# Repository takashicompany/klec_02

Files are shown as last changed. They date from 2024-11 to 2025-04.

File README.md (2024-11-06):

# KLEC-02 "Gravity-36"

https://x.com/Hottyhottea/status/1843859533871058982


# 部品リスト

|画像|部品名|個数|備考|
|:--|:--|:--|:--|
||KLEC-02 PCB|1||
||[Pro Micro](https://shop.yushakobo.jp/products/21)|2|どれを買っていいか分からない場合は[コンスルー付きのセット](https://shop.yushakobo.jp/products/21)の購入を推奨します。|
||[タクトスイッチ](https://shop.yushakobo.jp/products/a0800ts-01-1)|2||
||[コンスルー](https://shop.yushakobo.jp/products/31)|4|PCBとPro Microを接続する端子です。Pro Microに付属するピンヘッダでの取り付けも可能ですが、作業ミスや故障した際の取り替えが容易になりますので、**コンスルーの使用を強く推奨します。ピンヘッダでの取り付けは当キーボードと当ビルドガイドではサポートしません。** コンスルーの必要な高さはPro Microによって異なりますので、販売元にご確認ください。コンスルーについての詳細な説明は[こちら](https://scrapbox.io/self-made-kbds-ja/%E3%82%B3%E3%83%B3%E3%82%B9%E3%83%AB%E3%83%BC)をご一読ください。併せて[取り付け方の説明](https://yushakobo.zendesk.com/hc/ja/articles/360044233974-%E3%82%B3%E3%83%B3%E3%82%B9%E3%83%AB%E3%83%BC-%E3%82%B9%E3%83%97%E3%83%AA%E3%83%B3%E3%82%B0%E3%83%94%E3%83%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)も目を通しておくと作業がスムーズに進められます。|
||[スイッチソケット MX用](https://shop.yushakobo.jp/products/a01ps)|36|使用せずとも、PCBとキースイッチをハンダ付けすることで取り付けは可能ですが、メンテナンス性と組み立て手順を間違えた際のリカバリーを考慮すると、スイッチソケットを使用することを推奨します。|
||[MX互換キースイッチ](https://shop.yushakobo.jp/collections/all-switches)|36||
||[MX互換キーキャップ](https://shop.yushakobo.jp/collections/keycaps)|36|[こちら](https://www.keyboard-layout-editor.com/#/gists/d532e57cda0be36ffc0e33e7f8f69d8d)から各キーのサイズを確認できます。|
||[ウレタンクッション](https://shop.yushakobo.jp/products/a0800ur-01-6)|12|数はお好みで増減させてください。|
||アクリルケース|1|[こちらのデータ](https://github.com/takashicompany/klec_02/blob/master/case/klec_02_a4_yushakobo.ai)を遊舎工房の[レーザー加工サービス](https://shop.yushakobo.jp/products/lasercut?variant=48787700744423)にてカット依頼するなどして製造してください。後日に[キーボードアクリルプレート](https://shop.yushakobo.jp/products/keyboard_acrylic_plate)に追加予定です。|
||[M2スペーサー](https://shop.yushakobo.jp/products/a0800c2?variant=37665435222177)|12|長さはお好みで調整してください。Pro Microなどにもよりますが、7mm~10mmぐらいがオススメです。|
||[M2ネジ 5mm](https://shop.yushakobo.jp/products/a0800n2?variant=37665432993953)|24||

# ファームウェア
QMK Firmwareへの[プルリクエストはこちら](https://github.com/qmk/qmk_firmware/pull/24559)です。

VIAに対応したファームウェアは[こちら](https://github.com/takashicompany/klec_02/blob/master/via/takashicompany_klec_02_via.hex)です。ソースコードは[こちら](https://github.com/takashicompany/qmk_firmware/tree/master/keyboards/takashicompany/klec_02/keymaps/via)になります。

[RemapからWebブラウザを用いたファームウェアの書き込み](https://remap-keys.app/keyboards/jiZA8wP7nL4qwY1EUZ8j)とキーマップの変更が可能です。

~2024年11月5日現在、Remapの審査中ですのでRemapでキーマップを変更したい場合は[こちらのjsonファイル](https://github.com/takashicompany/klec_02/blob/master/via/via.json)をアップロードしてご利用ください。~

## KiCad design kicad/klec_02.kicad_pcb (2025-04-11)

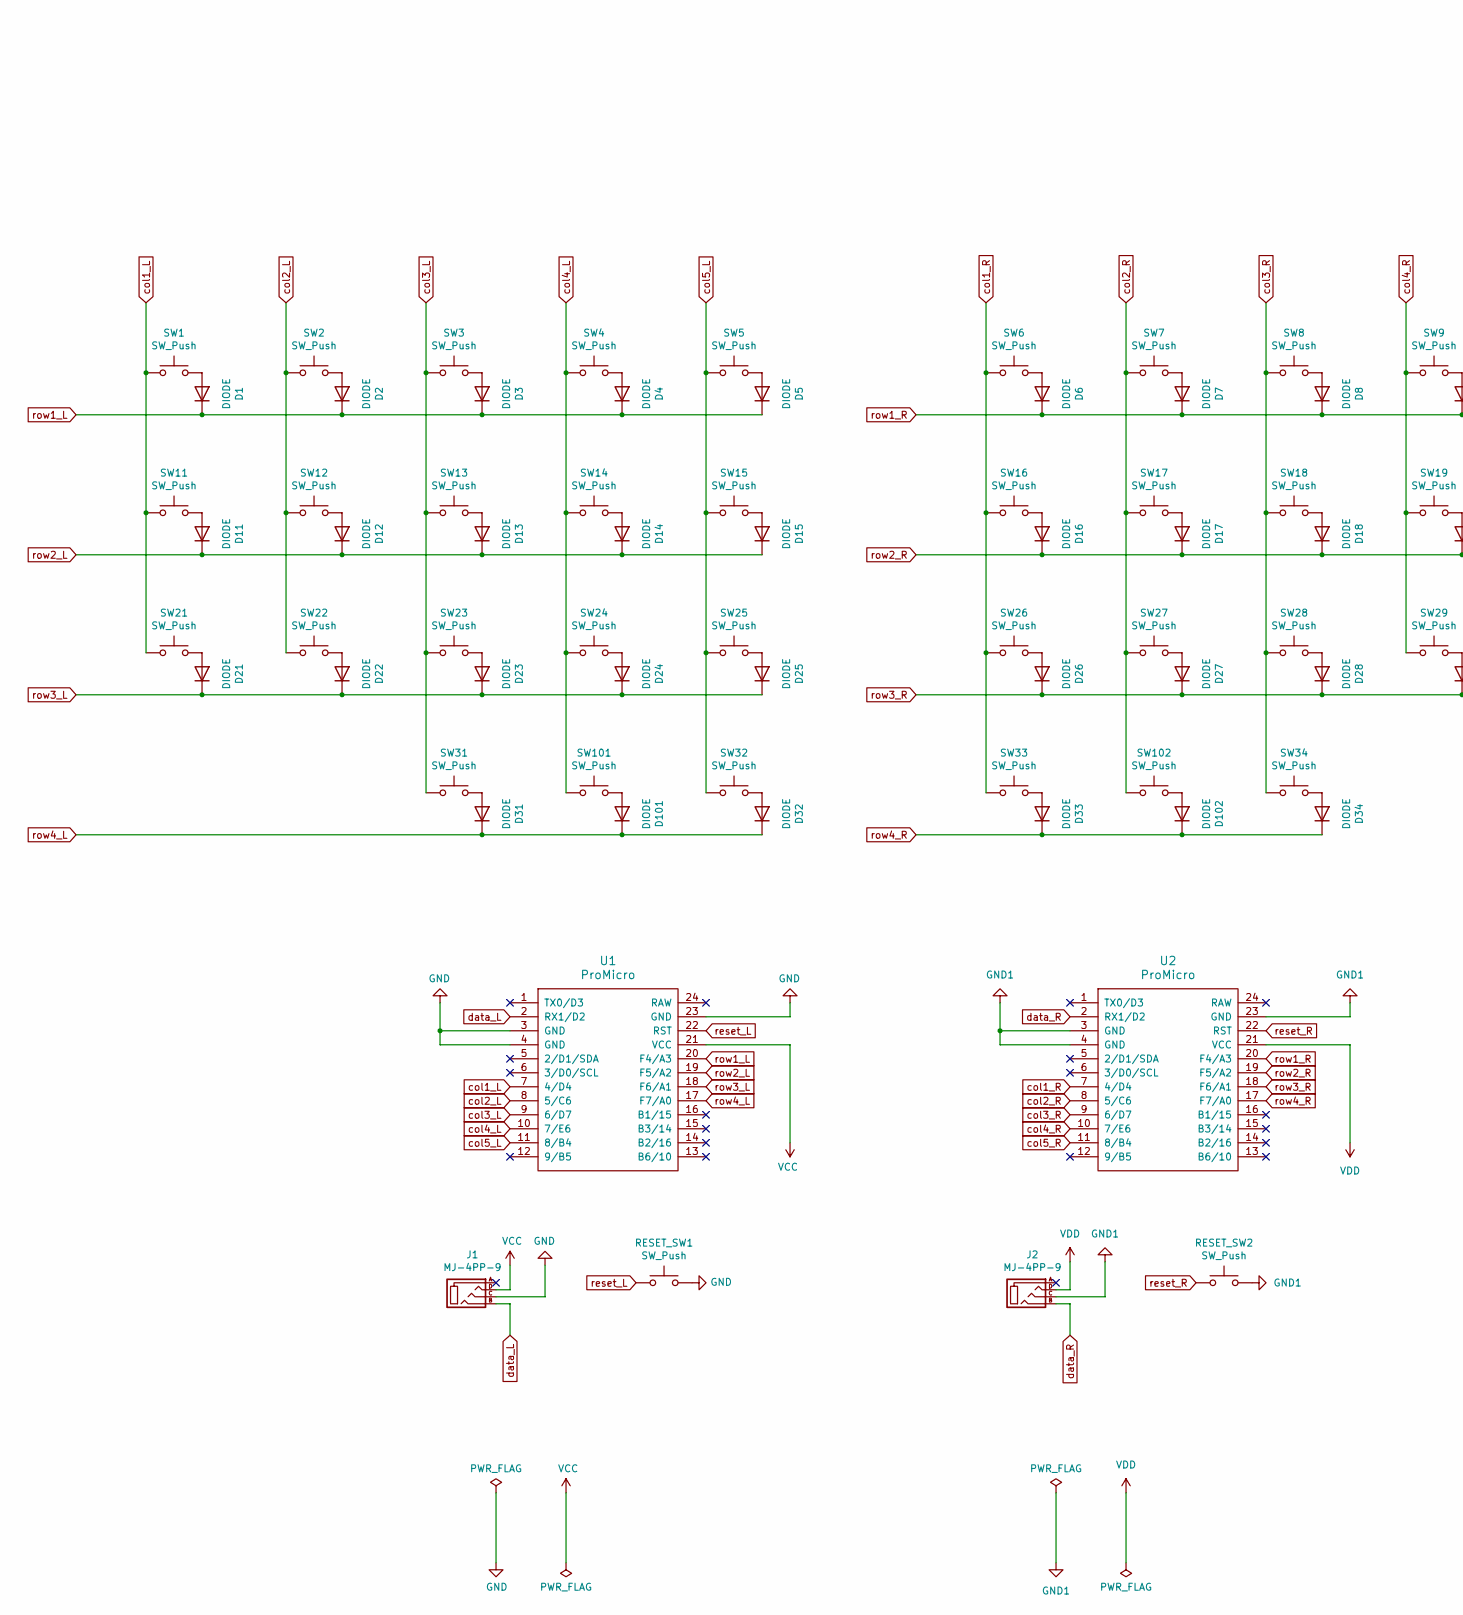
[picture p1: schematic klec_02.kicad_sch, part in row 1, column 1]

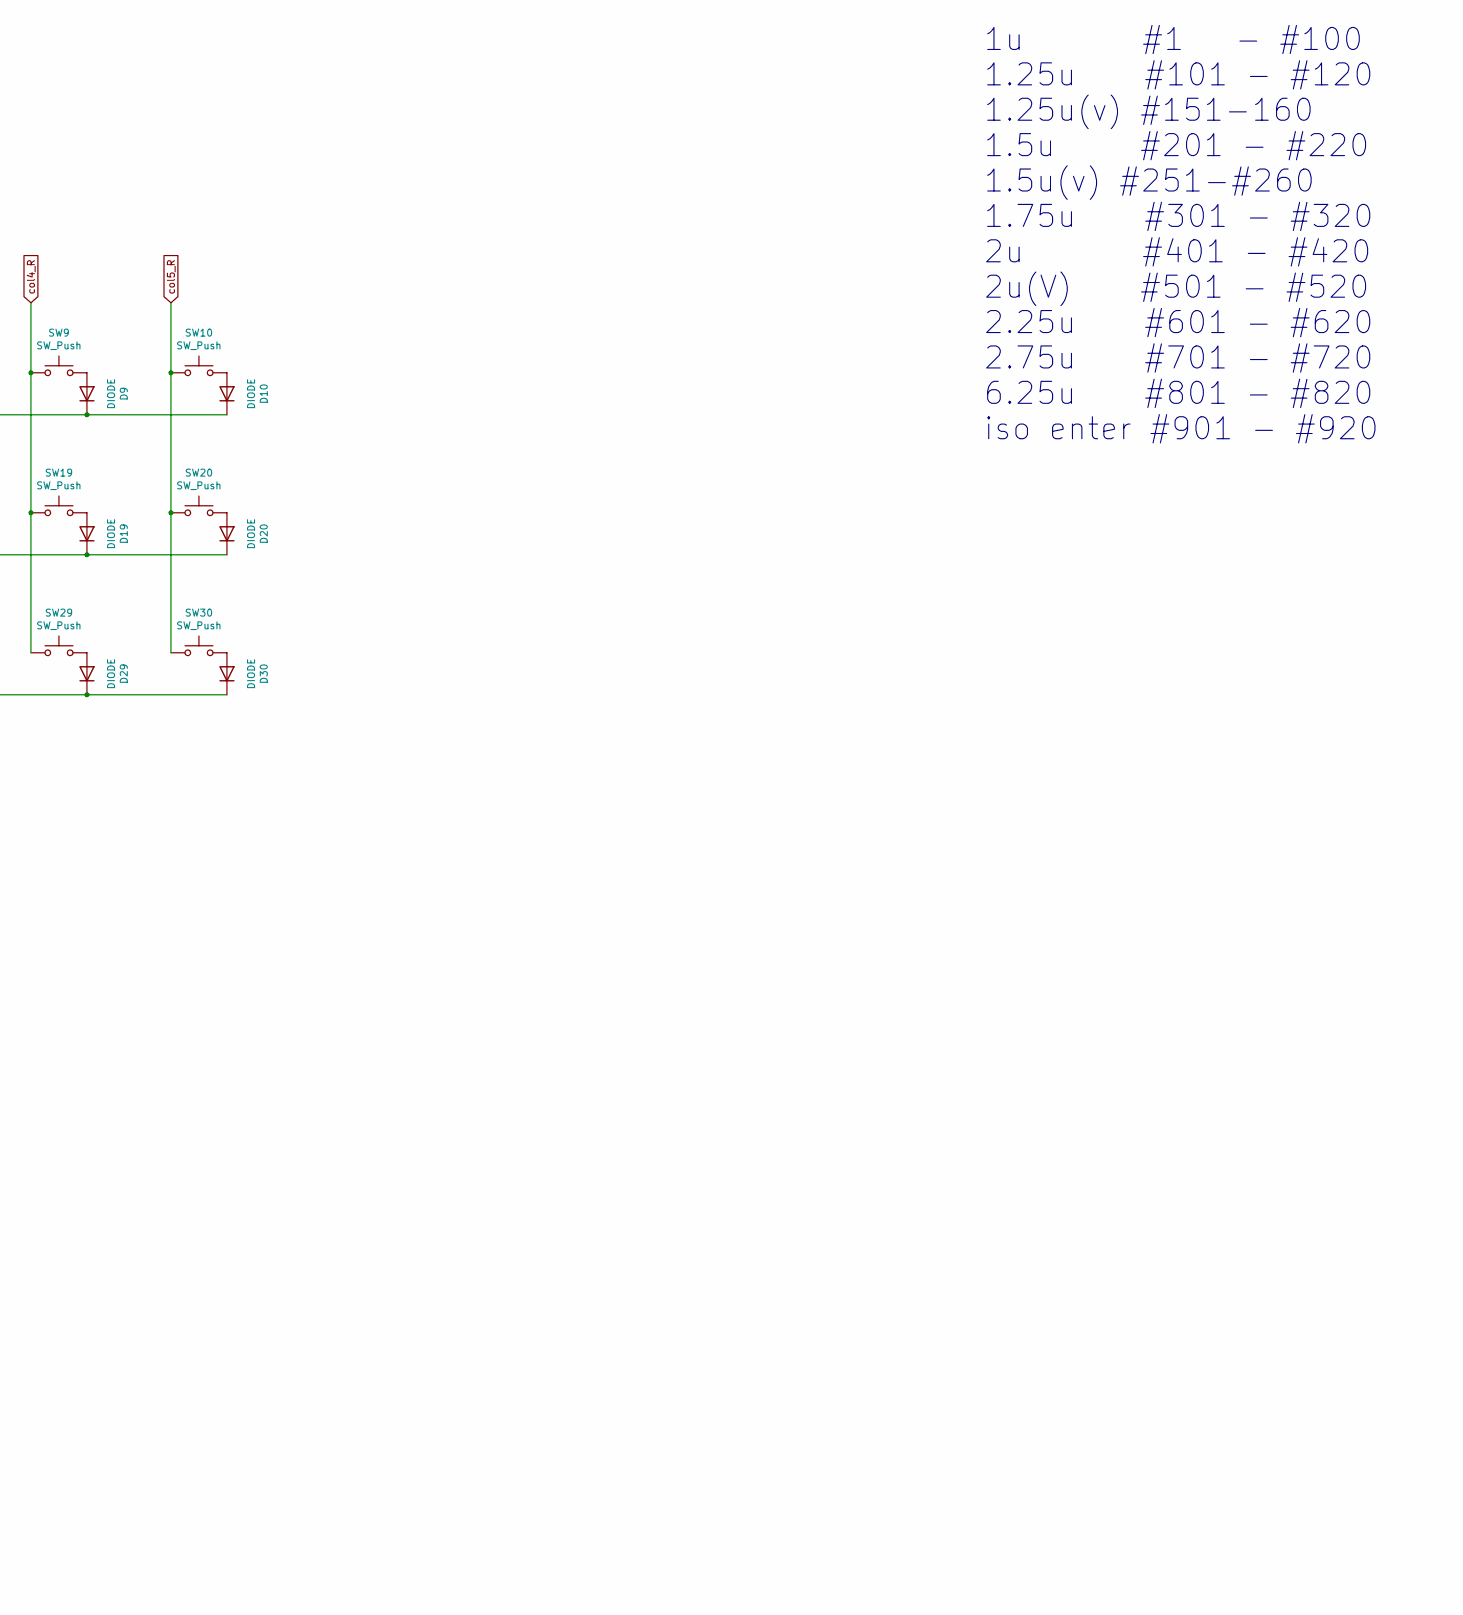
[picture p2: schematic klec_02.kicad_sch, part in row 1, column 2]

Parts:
D1, D2, D3, D4, D5, D6, D7, D8, D9, D10, D11, D12, D13, D14, D15, D16, D17, D18, D19, D20, D21, D22, D23, D24, D25, D26, D27, D28, D29, D30, D31, D32, D33, D34, D101, D102: DIODE; D3_TH_SMD_v2
J1, J2: MJ-4PP-9; MJ-4PP-9_1side
RESET_SW1, RESET_SW2: SW_Push; ResetSW_1side
SW1, SW2, SW3, SW4, SW5, SW6, SW7, SW8, SW9, SW10, SW11, SW12, SW13, SW14, SW15, SW16, SW17, SW18, SW19, SW20, SW21, SW22, SW23, SW24, SW25, SW26, SW27, SW28, SW29, SW30, SW31, SW32, SW33, SW34: SW_Push; CherryMX_TH-Hotswap
SW101, SW102: SW_Push; CherryMX_TH-Hotswap_1.25u
U1, U2: ProMicro; ProMicro_v3.5_print-inside_back

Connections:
GND: J1.C, RESET_SW1.2, U1.3 (GND), U1.4 (GND), U1.23 (GND)
GND1: J2.C, RESET_SW2.2, U2.3 (GND), U2.4 (GND), U2.23 (GND)
unnamed: D1.2 (A), SW1.2
unnamed: D2.2 (A), SW2.2
unnamed: D3.2 (A), SW3.2
unnamed: D4.2 (A), SW4.2
unnamed: D5.2 (A), SW5.2
unnamed: D6.2 (A), SW6.2
unnamed: D7.2 (A), SW7.2
unnamed: D8.2 (A), SW8.2
unnamed: D9.2 (A), SW9.2
unnamed: D10.2 (A), SW10.2
unnamed: D11.2 (A), SW11.2
unnamed: D12.2 (A), SW12.2
unnamed: D13.2 (A), SW13.2
unnamed: D14.2 (A), SW14.2
unnamed: D15.2 (A), SW15.2
unnamed: D16.2 (A), SW16.2
unnamed: D17.2 (A), SW17.2
unnamed: D18.2 (A), SW18.2
unnamed: D19.2 (A), SW19.2
unnamed: D20.2 (A), SW20.2
unnamed: D21.2 (A), SW21.2
unnamed: D22.2 (A), SW22.2
unnamed: D23.2 (A), SW23.2
unnamed: D24.2 (A), SW24.2
unnamed: D25.2 (A), SW25.2
unnamed: D26.2 (A), SW26.2
unnamed: D27.2 (A), SW27.2
unnamed: D28.2 (A), SW28.2
unnamed: D29.2 (A), SW29.2
unnamed: D30.2 (A), SW30.2
unnamed: D31.2 (A), SW31.2
unnamed: D32.2 (A), SW32.2
unnamed: D33.2 (A), SW33.2
unnamed: D34.2 (A), SW34.2
unnamed: D101.2 (A), SW101.2
unnamed: D102.2 (A), SW102.2
VCC: J1.D, U1.21 (VCC)
VDD: J2.D, U2.21 (VCC)
col1_L: SW1.1, SW11.1, SW21.1, U1.7 (4/D4)
col1_R: SW6.1, SW16.1, SW26.1, SW33.1, U2.7 (4/D4)
col2_L: SW2.1, SW12.1, SW22.1, U1.8 (5/C6)
col2_R: SW7.1, SW17.1, SW27.1, SW102.1, U2.8 (5/C6)
col3_L: SW3.1, SW13.1, SW23.1, SW31.1, U1.9 (6/D7)
col3_R: SW8.1, SW18.1, SW28.1, SW34.1, U2.9 (6/D7)
col4_L: SW4.1, SW14.1, SW24.1, SW101.1, U1.10 (7/E6)
col4_R: SW9.1, SW19.1, SW29.1, U2.10 (7/E6)
col5_L: SW5.1, SW15.1, SW25.1, SW32.1, U1.11 (8/B4)
col5_R: SW10.1, SW20.1, SW30.1, U2.11 (8/B4)
data_L: J1.B, U1.2 (RX1/D2)
data_R: J2.B, U2.2 (RX1/D2)
reset_L: RESET_SW1.1, U1.22 (RST)
reset_R: RESET_SW2.1, U2.22 (RST)
row1_L: D1.1 (K), D2.1 (K), D3.1 (K), D4.1 (K), D5.1 (K), U1.20 (F4/A3)
row1_R: D6.1 (K), D7.1 (K), D8.1 (K), D9.1 (K), D10.1 (K), U2.20 (F4/A3)
row2_L: D11.1 (K), D12.1 (K), D13.1 (K), D14.1 (K), D15.1 (K), U1.19 (F5/A2)
row2_R: D16.1 (K), D17.1 (K), D18.1 (K), D19.1 (K), D20.1 (K), U2.19 (F5/A2)
row3_L: D21.1 (K), D22.1 (K), D23.1 (K), D24.1 (K), D25.1 (K), U1.18 (F6/A1)
row3_R: D26.1 (K), D27.1 (K), D28.1 (K), D29.1 (K), D30.1 (K), U2.18 (F6/A1)
row4_L: D31.1 (K), D32.1 (K), D101.1 (K), U1.17 (F7/A0)
row4_R: D33.1 (K), D34.1 (K), D102.1 (K), U2.17 (F7/A0)

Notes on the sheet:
1u #1 - #100 1.25u #101 - #120 1.25u(v) #151-160 1.5u #201 - #220 1.5u(v) #251-#260 1.75u #301 - #320 2u #401 - #420 2u(V) #501 - #520 2.25u #601 - #620 2.75u #701 - #720 6.25u #801 - #820 iso enter #901 - #920

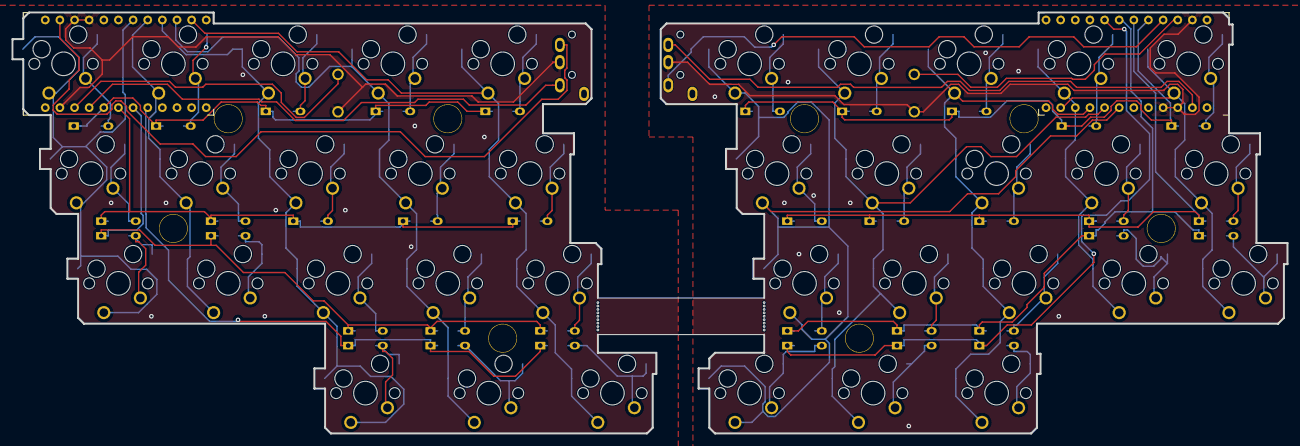
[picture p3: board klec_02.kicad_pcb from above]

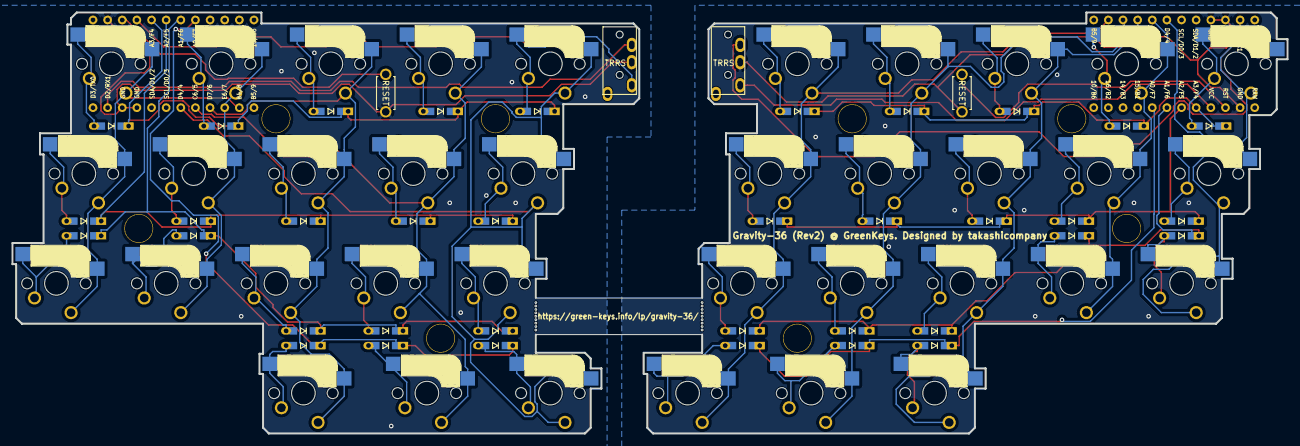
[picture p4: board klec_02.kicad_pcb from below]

Board: 2 copper layers, 221.3 x 73.0 mm, 88 parts (40 on the bottom side), 62 nets.

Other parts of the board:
BT1, BT2: Breakaway_Tabs
Hole1, Hole2, Hole3, Hole4, Hole5, Hole6, Hole7, Hole8: Val**; HOLE

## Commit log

2024-11-05 viaのjson
2025-02-23 svgを再アップロード
2025-04-11 add kicad
    [klec_02.kicad_pcb, klec_02.kicad_sch]
